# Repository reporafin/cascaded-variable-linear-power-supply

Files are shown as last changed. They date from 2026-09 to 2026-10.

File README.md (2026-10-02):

# Cascaded Multi-Rail AC-DC Linear Power Supply

A hardware design and simulation repository for a custom variable linear AC-to-DC power supply. The circuit relies on the LM adjustable voltage regulator and the fixed voltage regulators to provide stable, clean power for lab and prototyping environments. 

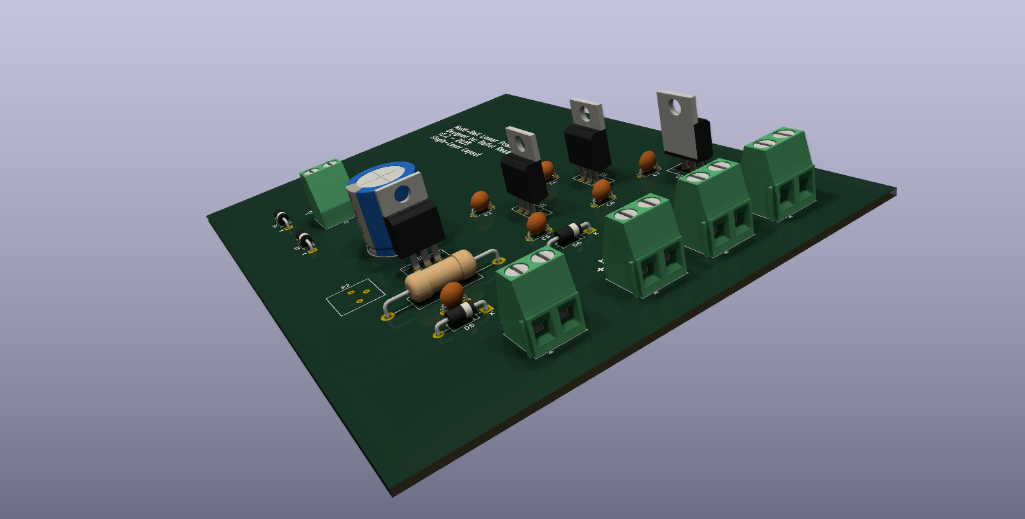
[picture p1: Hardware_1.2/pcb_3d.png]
3D Board Render


## Features
* **Multi-Rail Output:** Provides four distinct power rails: an adjustable output (1.25V–21V) via an LM317, and three fixed digital logic rails (12V, 5V, 3.3V).
* **Cascaded Architecture:** The fixed voltage regulators (LM7812, LM7805, and a LM-1117) are strategically cascaded. The main 34V DC bus feeds the 12V IC, which feeds the 5V IC, which finally feeds the LM1117-3.3 LDO to provide a clean 3.3V logic rail. This distributes thermal dissipation across the board and prevents the lower-voltage ICs from instantly overheating.
* **Thermal & Layout Optimization:** Designed on a strictly single-layer PCB using a manual 1.0mm common ground bus to safely manage continuous current and heat.
* **Safety & Transient Protection:** Integrated 1N4007 flywheel (flyback) diodes in reverse-biased parallel across the LM317 and LM7812 regulators. This creates a safe discharge path for output capacitors and protects the silicon from reverse-current spikes during power-off events.
* **Validated Design:** Component tolerances, inductive flyback protection, and ripple voltages across the cascaded rails were verified in LTspice prior to physical layout.

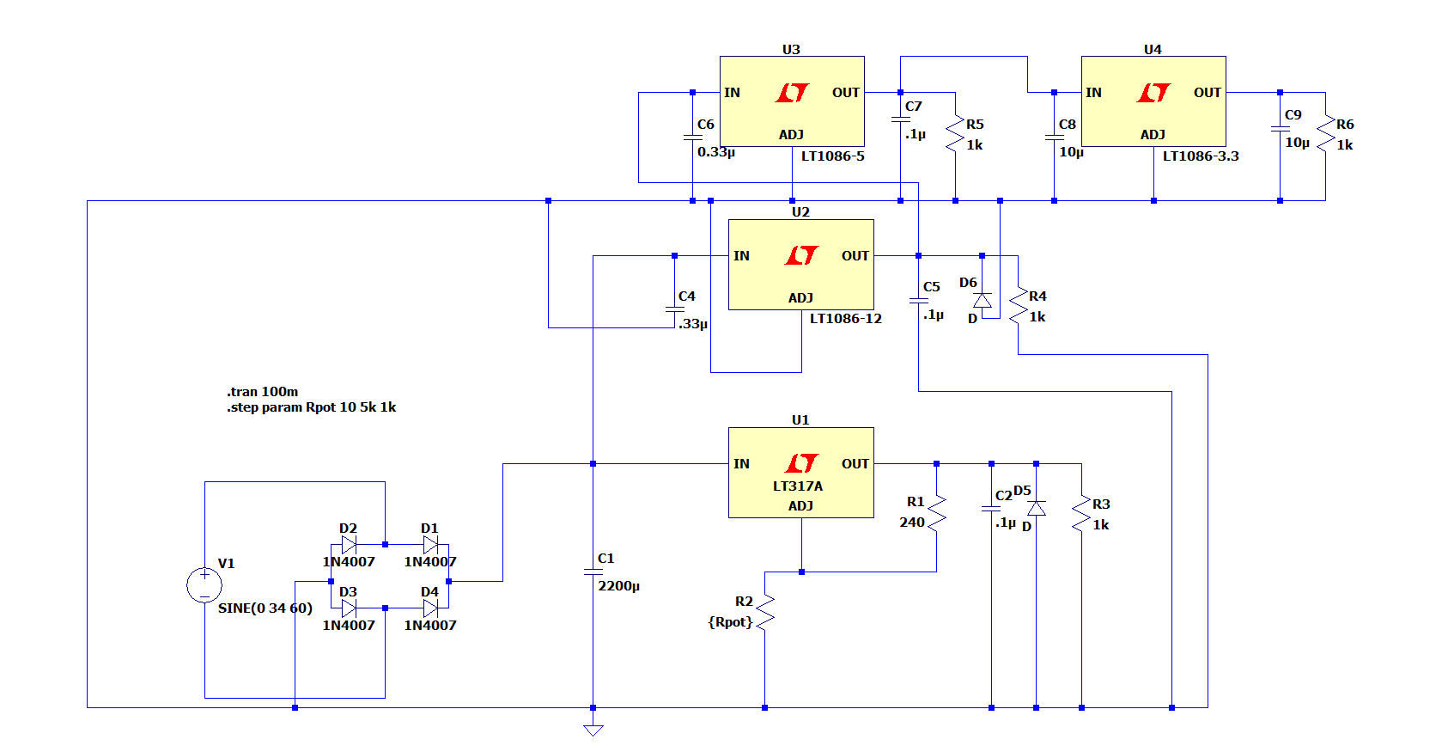
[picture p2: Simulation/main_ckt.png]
LTspice Schematic


## Repository Structure

```text
├── simulation/  # LTspice simulation files and waveform plots
├── hardware/    # KiCad schematics, PCB layout, and 3D models
│   └── gerbers/ # Manufacturing files for PCB fabrication
├── hardware_1.2/ # New KiCad schematics, PCB layout, and 3D models with some minor changes
│   └── gerbers/ # Manufacturing files for New PCB fabrication
└── README.md
```

## Prerequisites

To view or modify the files in this project, you will need:
* **[LTspice](https://www.analog.com/en/design-center/design-tools-and-calculators/ltspice-simulator.html):** For running the `.asc` circuit simulations.
* **[KiCad (v7.0+)](https://www.kicad.org/):** For opening the schematic and PCB files.

## Getting Started

1. **Simulation:** Open `Simulation/main_design.asc` in LTspice and click 'Run' to view the transient analysis and ripple voltages.
2. **Hardware:** Open `Hardware_1.2/vdc.kicad_pro` in KiCad to explore the schematic and PCB layout.
3. **Fabrication:** The production-ready Gerber files are located in `hardware/gerbers/`.

## License
This project is open-source and available under the [MIT License](LICENSE).

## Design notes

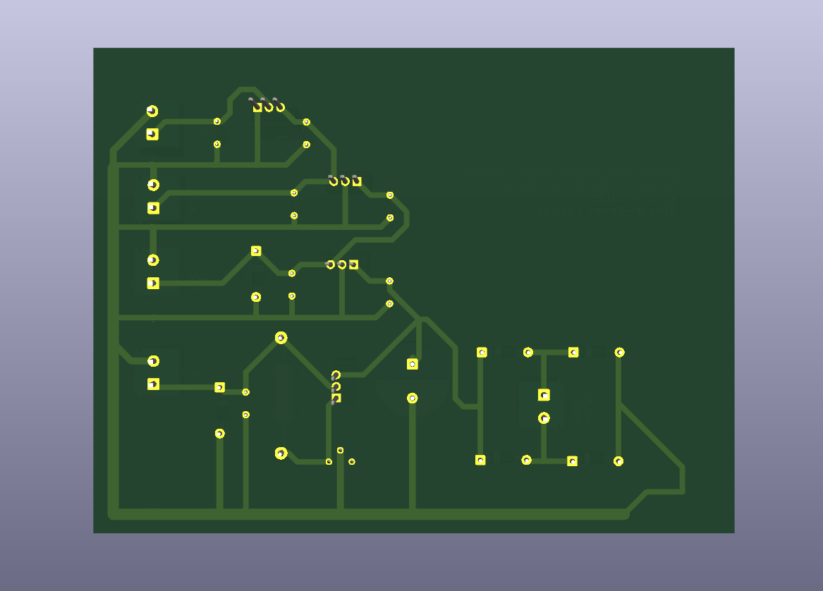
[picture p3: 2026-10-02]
Hardware_1.2/pcb_bottom_view.png

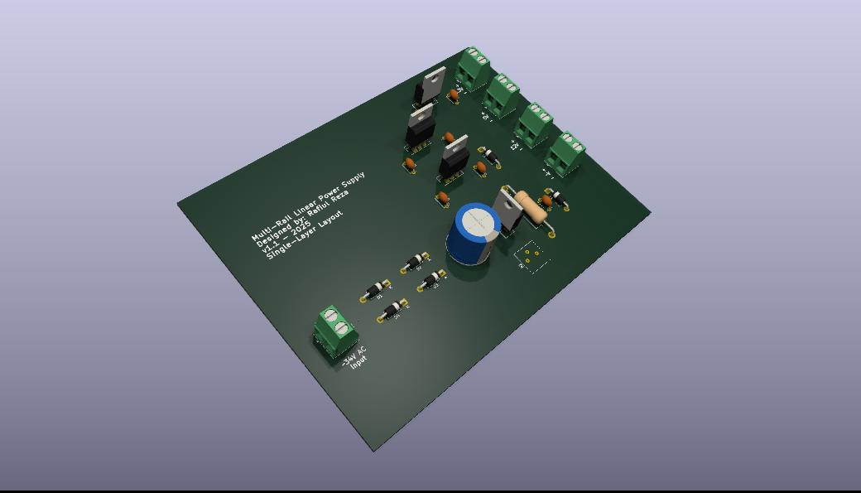
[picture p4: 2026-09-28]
Hardware/pcb_3d.png

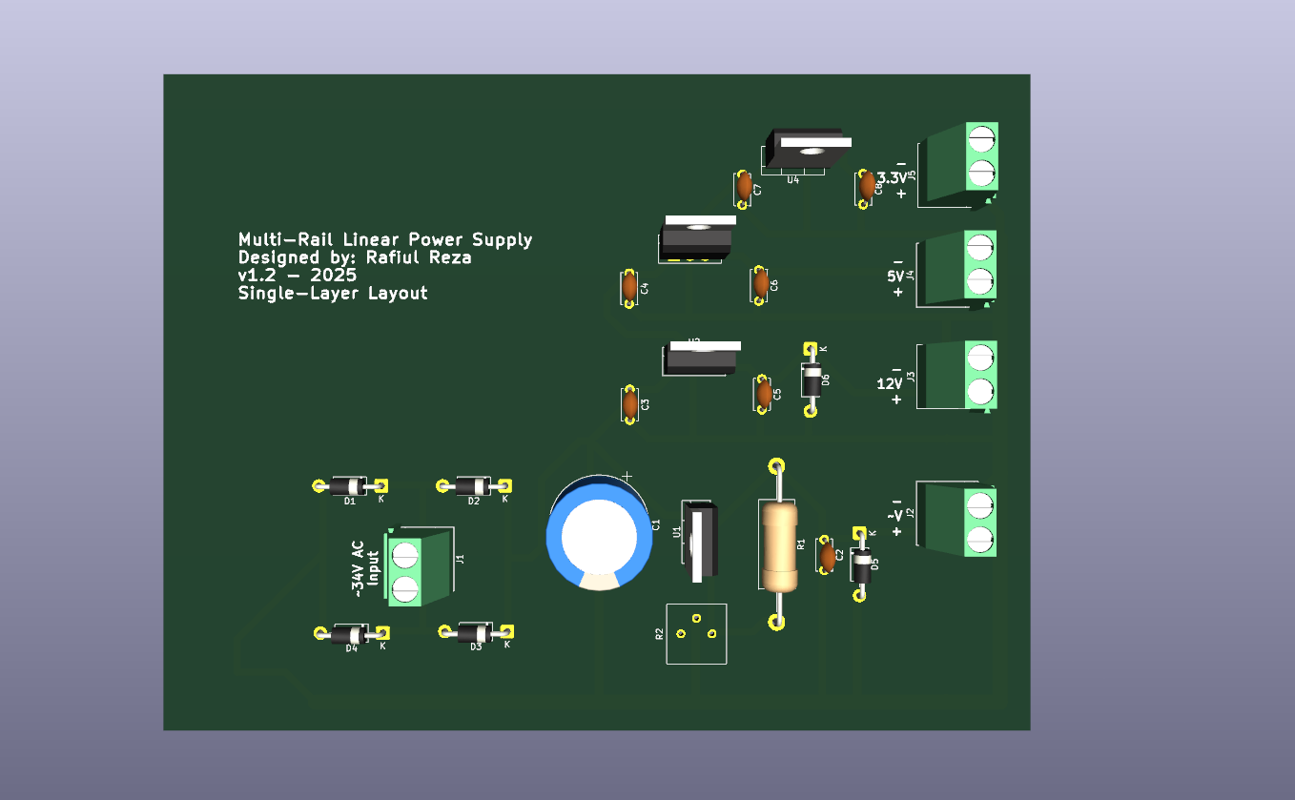
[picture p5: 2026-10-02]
Hardware_1.2/pcb_top_view.png

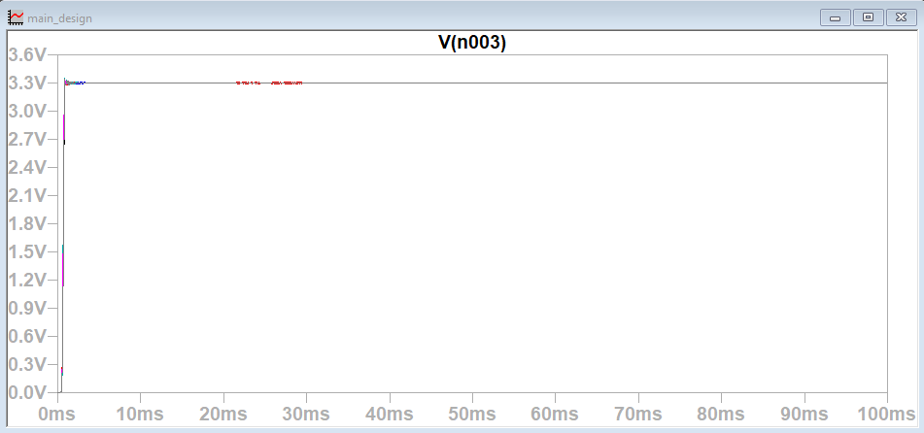
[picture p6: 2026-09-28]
Simulation/3.3V_output_plot.png

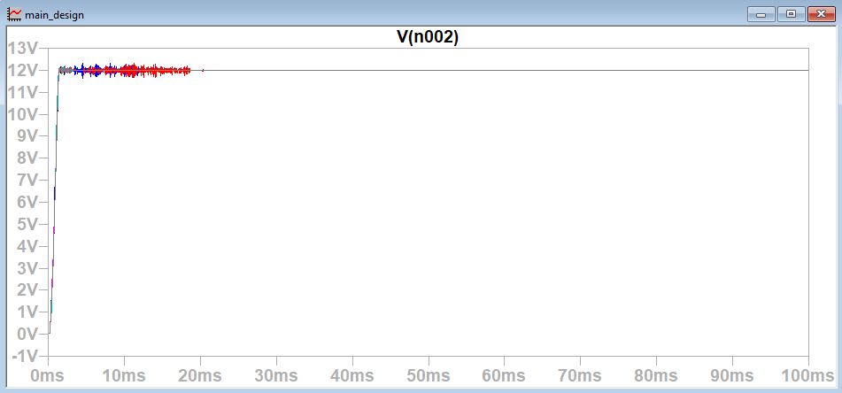
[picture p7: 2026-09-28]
Simulation/12V_output_plot.png

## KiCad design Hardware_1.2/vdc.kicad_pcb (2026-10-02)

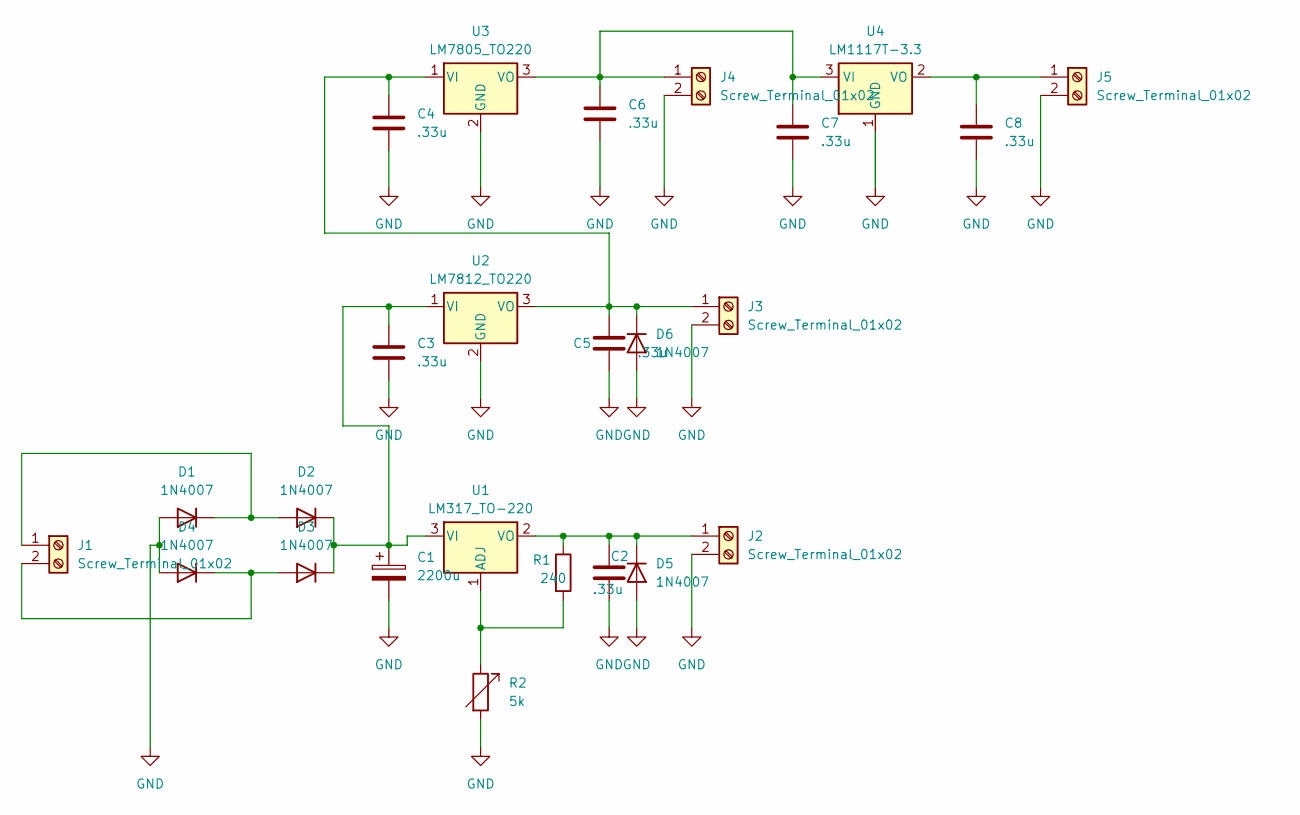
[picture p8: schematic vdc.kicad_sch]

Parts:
C1: 2200u; CP_Radial_D16.0mm_P7.50mm
C2, C3, C4, C5, C6, C7, C8: .33u; C_Disc_D5.0mm_W2.5mm_P5.00mm
D1, D2, D3, D4, D5, D6: 1N4007; D_DO-41_SOD81_P10.16mm_Horizontal
J1, J2, J3, J4, J5: Screw_Terminal_01x02; TerminalBlock_Phoenix_MKDS-1,5-2-5.08_1x02_P5.08mm_Horizont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
R1: 240; R_Axial_DIN0614_L14.3mm_D5.7mm_P25.40mm_Horizontal
R2: 5k; Potentiometer_Bourns_3386P_Vertical
U1: LM317_TO-220; TO-220-3_Vertical
U2: LM7812_TO220; TO-220-3_Vertical
U3: LM7805_TO220; TO-220-3_Vertical
U4: LM1117T-3.3; TO-220-3_Vertical

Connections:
GND: C1.2, C2.2, C3.2, C4.2, C5.2, C6.2, C7.2, C8.2, D1.2 (A), D4.2 (A), D5.2 (A), D6.2 (A), J2.2, J3.2, J4.2, J5.2, R2.2, U2.2 (GND), U3.2 (GND), U4.1 (GND)
unnamed: D1.1 (K), D2.2 (A), J1.1
unnamed: C1.1, C3.1, D2.1 (K), D3.1 (K), U1.3 (VI), U2.1 (VI)
unnamed: D3.2 (A), D4.1 (K), J1.2
unnamed: C2.1, D5.1 (K), J2.1, R1.1, U1.2 (VO)
unnamed: C4.1, C5.1, D6.1 (K), J3.1, U2.3 (VO), U3.1 (VI)
unnamed: C6.1, C7.1, J4.1, U3.3 (VO), U4.3 (VI)
unnamed: C8.1, J5.1, U4.2 (VO)
unnamed: R1.2, R2.1, U1.1 (ADJ)

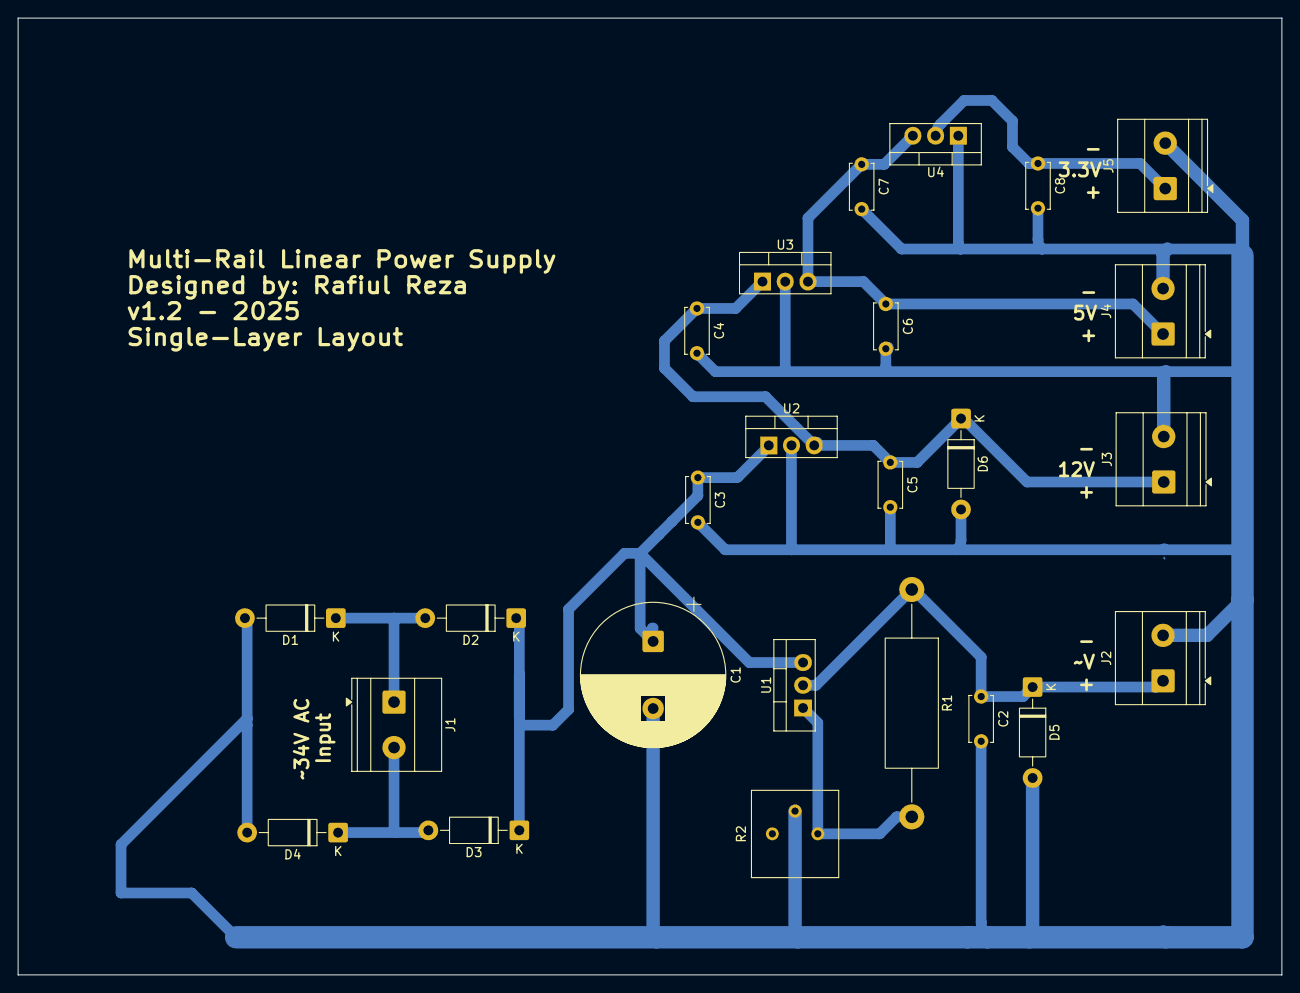
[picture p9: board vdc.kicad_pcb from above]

Board: 2 copper layers, 141.2 x 106.9 mm, 25 parts (0 on the bottom side), 9 nets.
